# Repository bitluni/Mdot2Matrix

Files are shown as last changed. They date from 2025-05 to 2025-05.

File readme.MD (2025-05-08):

# M.2 LED Matrix

## Goal

This project is a showcase and starting point for M.2 PCIe hardware. The interface chip CH382 was used to inteface between the first PCIe lane and the CH32V208 MCU over UART.
Check out the [versionProject video](https://youtu.be/yxVQkL01FD4)

## State

RTS and DTR control flow signals are used to put the MCU into bootloader. !Caution This version is not working correctly as the signals are flipped on boot etc. Here is an updated [version](https://www.falstad.com/circuit/circuitjs.html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)

In general the interface chip draws 170mA which puts the little LDO at it's limit. The thermals are terrible. Would not recomment to use this setup for a commercial project without a severe refinement.

## Tools

The firmware can be uploaded via the [wch web isp](https://github.com/basilhussain/wch-web-isp)

The code is written with the [MounRiver Studio](http://www.mounriver.com/download)

Node.js is required to run the websocket server

## Vibe coding

The majority of the web tool and the server are generated with ChatGPT which was trained on dacades of mine and your public code.

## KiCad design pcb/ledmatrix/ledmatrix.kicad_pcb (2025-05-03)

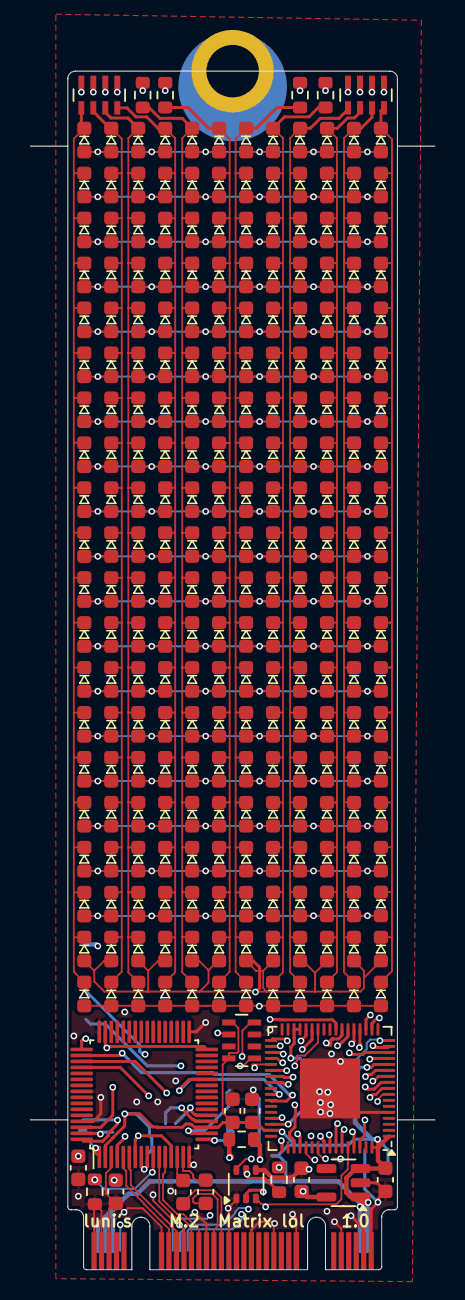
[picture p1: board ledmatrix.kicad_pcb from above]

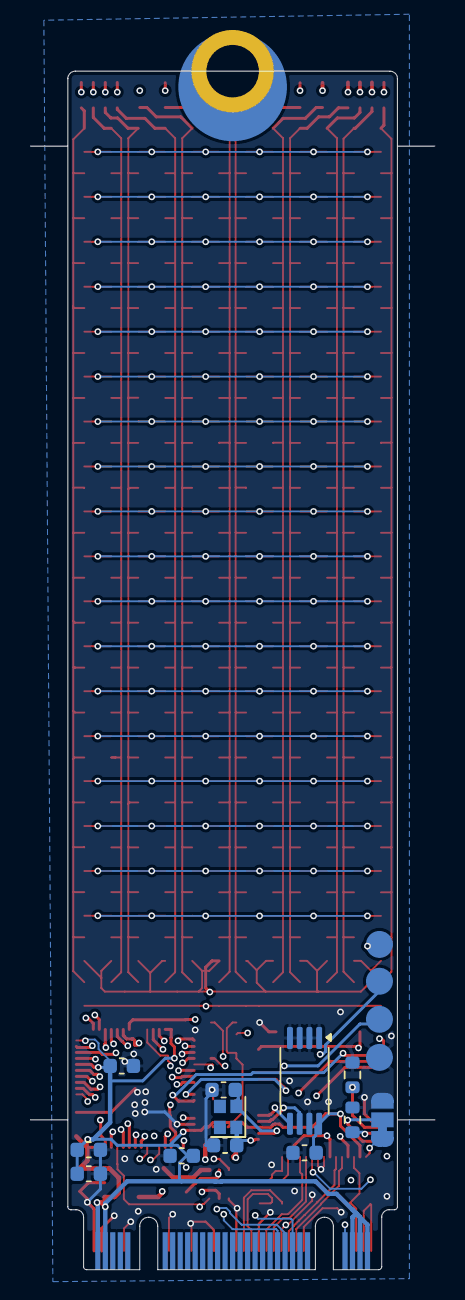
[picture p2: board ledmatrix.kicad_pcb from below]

Board: 4 copper layers, 22.0 x 80.0 mm, 276 parts (13 on the bottom side), 77 nets.

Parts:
C1, C2, C3, C10, C12, C15, C21, C22, C23, C24, C25: 100n; C_0603_1608Metric
C8, C11: 10u; C_0603_1608Metric
C16, C17: 27p; C_0603_1608Metric
D121, D122, D123, D124, D125, D126, D127, D128, D129, D130, D131, D132, D133, D134, D135, D136, D137, D138, D139, D140, D141, D142, D143, D144, D145, D146, D147, D148, D149, D150, D151, D152, D153, D154, D155, D156, D157, D158, D159, D160, D161, D162, D163, D164, D165, D166, D167, D168, D169, D170, D171, D172, D173, D174, D175, D176, D177, D178, D179, D180, D181, D182, D183, D184, D185, D186, D187, D188, D189, D190, D191, D192, D193, D194, D195, D196, D197, D198, D199, D200, D201, D202, D203, D204, D205, D206, D207, D208, D209, D210, D211, D212, D213, D214, D215, D216, D217, D218, D219, D220, D221, D222, D223, D224, D225, D226, D227, D228, D229, D230, D231, D232, D233, D234, D235, D236, D237, D238, D239, D240, D241, D242, D243, D244, D245, D246, D247, D248, D249, D250, D251, D252, D253, D254, D255, D256, D257, D258, D259, D260, D261, D262, D263, D264, D265, D266, D267, D268, D269, D270, D271, D272, D273, D274, D275, D276, D277, D278, D279, D280, D281, D282, D283, D284, D285, D286, D287, D288, D289, D290, D291, D292, D293, D294, D295, D296, D297, D298, D299, D300, D301, D302, D303, D304, D305, D306, D307, D308, D309, D310, D311, D312, D313, D314, D315, D316, D317, D318, D319, D320, D321, D322, D323, D324, D325, D326, D327, D328, D329, D330, D331, D332, D333, D334, D335, D336, D337, D338, D339, D340, D341, D342, D343, D344, D345, D346, D347, D348, D349, D350, D351, D352, D353, D354, D355, D356, D357, D358, D359, D360: LEDdiag0603; LED_0603
JP2: Jumper_3_Bridged12; SolderJumper-3_P1.3mm_Bridged12_RoundedPad1.0x1.5mm
Q1: UMH3N; SOT-363_SC-70-6
R8, R13, R14, R15, R16: 1k; R_0603_1608Metric
R9, R10, R11: 0; R_0603_1608Metric
R12: 12k; R_0603_1608Metric
RN5, RN6: 1k; R_Array_Concave_4x0603
RN8: 10k; R_Array_Concave_4x0603
TP1: TestPoint; Testpoint4
U1: CH382; LQFP-64_7x7mm_P0.4mm
U2: M.2-B+M-KEY-PCIe; M.2-B+M-KEY 2280
U4: M24C02-FDW; TSSOP-8_4.4x3mm_P0.65mm
U5: QFN-68-1EP_8x8mm_P0.4mm_EP4x4mm
U6: AP2112K-1.8; SOT-23-5
Y1: 22.1184MHz; Crystal_SMD_2016-4Pin_2.0x1.6mm

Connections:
1V8: C10.2, C11.2, R9.1, U1.4 (VCC18), U1.32 (VCC18), U1.47 (VCC18), U6.5 (VOUT)
1V8A: C12.2, R9.2, U1.7 (VCC18A), U1.13 (VCC18A)
/BOOT1: R8.2, U5.28 (PB2/BOOT1)
/CKSEL: JP2.2 (C), U1.64 (CKSEL)
/CLKREQ#: RN8.2 (R2.1), U2.P$52 (CLKREQ#)
/CLK_32k: U2.P$68 (SUSCLK(32kHz)), U5.58 (PB3)
/DTR: Q1.2 (B1), U1.52 (DTR0)
/PECK+: U1.5 (PECK+), U2.P$55 (REFCLK+)
/PECK-: U1.6 (PECK-), U2.P$53 (REFCLK-)
/PER+: U1.11 (PER+), U2.P$49 (PER0+)
/PER-: U1.12 (PER-), U2.P$47 (PER0-)
/PET+: C2.2, U1.15 (PET+)
/PET-: C1.2, U1.14 (PET-)
/RST#: JP2.1 (A), U1.1 (PERST#), U2.P$50 (PERST#)
/RST_CH32#: Q1.6 (C1), RN8.8 (R1.2), U5.8 (NRST)
/RTS: Q1.5 (B2), R8.1, U1.51 (RTS0)
/RX: U1.27 (RXD0), U5.44 (PA9)
/TX: U1.50 (TXD0), U5.45 (PA10)
/WAKE#: U2.P$54 (PEWAKE#), U5.56 (PC12)
BOOT0: Q1.3 (C2), RN8.5 (R4.2), U5.63 (BOOT0)
GND: C3.1, C8.1, C10.1, C11.1, C12.1, C15.1, C16.2, C17.2, C21.2, C22.2, C23.2, C24.2, C25.2, JP2.3 (B), Q1.1 (E1), Q1.4 (E2), R10.2, R11.2, R12.2, RN8.7 (R2.2), TP1.1, U1.3 (GND), U1.8 (GND), U1.9 (GND), U1.16 (GND), U1.33 (GND), U1.48 (GND), U1.56 (GND), U1.61 (GND), U2.P$1 (CONFIG3/GND), U2.P$3 (GND), U2.P$9 (GND), U2.P$21 (CONFIG_0/GND), U2.P$27 (GND), U2.P$33 (GND), U2.P$39 (GND), U2.P$45 (GND), U2.P$51 (GND), U2.P$57 (GND), U2.P$71 (GND), U2.P$73 (GND), U2.P$75 (CONFIG_2/GND), U4.1 (E0), U4.2 (E1), U4.3 (E2), U4.4 (VSS), U4.7 (~WC), U5.5 (VSSA), U5.49 (VSS_2), U5.69 (VSS), U6.2 (GND)
unnamed: D121.1 (K), D133.1 (K), D145.1 (K), D157.1 (K), D169.1 (K), D181.1 (K), D193.1 (K), D205.1 (K), D217.1 (K), D229.1 (K), D241.1 (K), D253.1 (K), D265.1 (K), D277.1 (K), D289.1 (K), D301.1 (K), D313.1 (K), D325.1 (K), D337.1 (K), D349.1 (K), RN5.4 (R4.1)
unnamed: D122.1 (K), D134.1 (K), D146.1 (K), D158.1 (K), D170.1 (K), D182.1 (K), D194.1 (K), D206.1 (K), D218.1 (K), D230.1 (K), D242.1 (K), D254.1 (K), D266.1 (K), D278.1 (K), D290.1 (K), D302.1 (K), D314.1 (K), D326.1 (K), D338.1 (K), D350.1 (K), RN5.3 (R3.1)
unnamed: D123.1 (K), D135.1 (K), D147.1 (K), D159.1 (K), D171.1 (K), D183.1 (K), D195.1 (K), D207.1 (K), D219.1 (K), D231.1 (K), D243.1 (K), D255.1 (K), D267.1 (K), D279.1 (K), D291.1 (K), D303.1 (K), D315.1 (K), D327.1 (K), D339.1 (K), D351.1 (K), RN5.2 (R2.1)
unnamed: D124.1 (K), D136.1 (K), D148.1 (K), D160.1 (K), D172.1 (K), D184.1 (K), D196.1 (K), D208.1 (K), D220.1 (K), D232.1 (K), D244.1 (K), D256.1 (K), D268.1 (K), D280.1 (K), D292.1 (K), D304.1 (K), D316.1 (K), D328.1 (K), D340.1 (K), D352.1 (K), RN5.1 (R1.1)
unnamed: D125.1 (K), D137.1 (K), D149.1 (K), D161.1 (K), D173.1 (K), D185.1 (K), D197.1 (K), D209.1 (K), D221.1 (K), D233.1 (K), D245.1 (K), D257.1 (K), D269.1 (K), D281.1 (K), D293.1 (K), D305.1 (K), D317.1 (K), D329.1 (K), D341.1 (K), D353.1 (K), R13.1
unnamed: D126.1 (K), D138.1 (K), D150.1 (K), D162.1 (K), D174.1 (K), D186.1 (K), D198.1 (K), D210.1 (K), D222.1 (K), D234.1 (K), D246.1 (K), D258.1 (K), D270.1 (K), D282.1 (K), D294.1 (K), D306.1 (K), D318.1 (K), D330.1 (K), D342.1 (K), D354.1 (K), R14.1
unnamed: D127.1 (K), D139.1 (K), D151.1 (K), D163.1 (K), D175.1 (K), D187.1 (K), D199.1 (K), D211.1 (K), D223.1 (K), D235.1 (K), D247.1 (K), D259.1 (K), D271.1 (K), D283.1 (K), D295.1 (K), D307.1 (K), D319.1 (K), D331.1 (K), D343.1 (K), D355.1 (K), R15.1
unnamed: D128.1 (K), D140.1 (K), D152.1 (K), D164.1 (K), D176.1 (K), D188.1 (K), D200.1 (K), D212.1 (K), D224.1 (K), D236.1 (K), D248.1 (K), D260.1 (K), D272.1 (K), D284.1 (K), D296.1 (K), D308.1 (K), D320.1 (K), D332.1 (K), D344.1 (K), D356.1 (K), R16.1
unnamed: D129.1 (K), D141.1 (K), D153.1 (K), D165.1 (K), D177.1 (K), D189.1 (K), D201.1 (K), D213.1 (K), D225.1 (K), D237.1 (K), D249.1 (K), D261.1 (K), D273.1 (K), D285.1 (K), D297.1 (K), D309.1 (K), D321.1 (K), D333.1 (K), D345.1 (K), D357.1 (K), RN6.4 (R4.1)
unnamed: D130.1 (K), D142.1 (K), D154.1 (K), D166.1 (K), D178.1 (K), D190.1 (K), D202.1 (K), D214.1 (K), D226.1 (K), D238.1 (K), D250.1 (K), D262.1 (K), D274.1 (K), D286.1 (K), D298.1 (K), D310.1 (K), D322.1 (K), D334.1 (K), D346.1 (K), D358.1 (K), RN6.3 (R3.1)
unnamed: D131.1 (K), D143.1 (K), D155.1 (K), D167.1 (K), D179.1 (K), D191.1 (K), D203.1 (K), D215.1 (K), D227.1 (K), D239.1 (K), D251.1 (K), D263.1 (K), D275.1 (K), D287.1 (K), D299.1 (K), D311.1 (K), D323.1 (K), D335.1 (K), D347.1 (K), D359.1 (K), RN6.2 (R2.1)
unnamed: D132.1 (K), D144.1 (K), D156.1 (K), D168.1 (K), D180.1 (K), D192.1 (K), D204.1 (K), D216.1 (K), D228.1 (K), D240.1 (K), D252.1 (K), D264.1 (K), D276.1 (K), D288.1 (K), D300.1 (K), D312.1 (K), D324.1 (K), D336.1 (K), D348.1 (K), D360.1 (K), RN6.1 (R1.1)
unnamed: R11.1, U1.62 (MDPRT#)
unnamed: R10.1, U1.63 (MDSEL)
unnamed: R12.1, U1.10 (RREF)
unnamed: U1.20 (SCL), U4.6 (SCL)
unnamed: U1.21 (SDA), U4.5 (SDA)
unnamed: C16.1, U1.18 (XI), Y1.2
unnamed: C17.1, U1.17 (XO), Y1.1
unnamed: C2.1, U2.P$43 (PET0+)
unnamed: C1.1, U2.P$41 (PET0-)
PA0: D121.2 (A), D122.2 (A), D123.2 (A), D124.2 (A), D125.2 (A), D126.2 (A), D127.2 (A), D128.2 (A), D129.2 (A), D130.2 (A), D131.2 (A), D132.2 (A), U5.14 (PA0/WKUP/ADC0)
PA1: D133.2 (A), D134.2 (A), D135.2 (A), D136.2 (A), D137.2 (A), D138.2 (A), D139.2 (A), D140.2 (A), D141.2 (A), D142.2 (A), D143.2 (A), D144.2 (A), U5.15 (PA1/ADC1)
PA2: D145.2 (A), D146.2 (A), D147.2 (A), D148.2 (A), D149.2 (A), D150.2 (A), D151.2 (A), D152.2 (A), D153.2 (A), D154.2 (A), D155.2 (A), D156.2 (A), U5.16 (PA2/ADC2)
PA3: D157.2 (A), D158.2 (A), D159.2 (A), D160.2 (A), D161.2 (A), D162.2 (A), D163.2 (A), D164.2 (A), D165.2 (A), D166.2 (A), D167.2 (A), D168.2 (A), U5.19 (PA3/ADC3)
PA4: D169.2 (A), D170.2 (A), D171.2 (A), D172.2 (A), D173.2 (A), D174.2 (A), D175.2 (A), D176.2 (A), D177.2 (A), D178.2 (A), D179.2 (A), D180.2 (A), U5.20 (PA4/ADC4)
PA5: D181.2 (A), D182.2 (A), D183.2 (A), D184.2 (A), D185.2 (A), D186.2 (A), D187.2 (A), D188.2 (A), D189.2 (A), D190.2 (A), D191.2 (A), D192.2 (A), U5.21 (PA5/ADC5)
PA6: D193.2 (A), D194.2 (A), D195.2 (A), D196.2 (A), D197.2 (A), D198.2 (A), D199.2 (A), D200.2 (A), D201.2 (A), D202.2 (A), D203.2 (A), D204.2 (A), U5.22 (PA6/ADC6)
PA7: D205.2 (A), D206.2 (A), D207.2 (A), D208.2 (A), D209.2 (A), D210.2 (A), D211.2 (A), D212.2 (A), D213.2 (A), D214.2 (A), D215.2 (A), D216.2 (A), U5.23 (PA7/ADC7)
PB4: D217.2 (A), D218.2 (A), D219.2 (A), D220.2 (A), D221.2 (A), D222.2 (A), D223.2 (A), D224.2 (A), D225.2 (A), D226.2 (A), D227.2 (A), D228.2 (A), U5.59 (PB4)
PB5: D229.2 (A), D230.2 (A), D231.2 (A), D232.2 (A), D233.2 (A), D234.2 (A), D235.2 (A), D236.2 (A), D237.2 (A), D238.2 (A), D239.2 (A), D240.2 (A), U5.60 (PB5)
PB6: D241.2 (A), D242.2 (A), D243.2 (A), D244.2 (A), D245.2 (A), D246.2 (A), D247.2 (A), D248.2 (A), D249.2 (A), D250.2 (A), D251.2 (A), D252.2 (A), U5.61 (PB6/USB2DM)
PB7: D253.2 (A), D254.2 (A), D255.2 (A), D256.2 (A), D257.2 (A), D258.2 (A), D259.2 (A), D260.2 (A), D261.2 (A), D262.2 (A), D263.2 (A), D264.2 (A), U5.62 (PB7/USB2DP)
PB8: D265.2 (A), D266.2 (A), D267.2 (A), D268.2 (A), D269.2 (A), D270.2 (A), D271.2 (A), D272.2 (A), D273.2 (A), D274.2 (A), D275.2 (A), D276.2 (A), U5.64 (PB8)
PB9: D277.2 (A), D278.2 (A), D279.2 (A), D280.2 (A), D281.2 (A), D282.2 (A), D283.2 (A), D284.2 (A), D285.2 (A), D286.2 (A), D287.2 (A), D288.2 (A), U5.65 (PB9)
PB10: D289.2 (A), D290.2 (A), D291.2 (A), D292.2 (A), D293.2 (A), D294.2 (A), D295.2 (A), D296.2 (A), D297.2 (A), D298.2 (A), D299.2 (A), D300.2 (A), U5.29 (PB10)
PB11: D301.2 (A), D302.2 (A), D303.2 (A), D304.2 (A), D305.2 (A), D306.2 (A), D307.2 (A), D308.2 (A), D309.2 (A), D310.2 (A), D311.2 (A), D312.2 (A), U5.30 (PB11)
PB12: D313.2 (A), D314.2 (A), D315.2 (A), D316.2 (A), D317.2 (A), D318.2 (A), D319.2 (A), D320.2 (A), D321.2 (A), D322.2 (A), D323.2 (A), D324.2 (A), U5.35 (PB12)
PB13: D325.2 (A), D326.2 (A), D327.2 (A), D328.2 (A), D329.2 (A), D330.2 (A), D331.2 (A), D332.2 (A), D333.2 (A), D334.2 (A), D335.2 (A), D336.2 (A), U5.36 (PB13)
PB14: D337.2 (A), D338.2 (A), D339.2 (A), D340.2 (A), D341.2 (A), D342.2 (A), D343.2 (A), D344.2 (A), D345.2 (A), D346.2 (A), D347.2 (A), D348.2 (A), U5.37 (PB14)
PB15: D349.2 (A), D350.2 (A), D351.2 (A), D352.2 (A), D353.2 (A), D354.2 (A), D355.2 (A), D356.2 (A), D357.2 (A), D358.2 (A), D359.2 (A), D360.2 (A), U5.38 (PB15)
PC0: RN5.5 (R4.2), U5.9 (PC0/ADC10)
PC1: RN5.6 (R3.2), U5.10 (PC1/ADC11)
PC2: RN5.7 (R2.2), U5.11 (PC2/ADC12)
PC3: RN5.8 (R1.2), U5.12 (PC3/ADC13)
PC4: R13.2, U5.24 (PC4/ADC14)
PC5: R14.2, U5.25 (PC5/ADC15)
PC6: R15.2, U5.39 (PC6/RXP)
PC7: R16.2, U5.40 (PC7/RXN)
PC8: RN6.5 (R4.2), U5.41 (PC8/TXP)
PC9: RN6.6 (R3.2), U5.42 (PC9/TXN)
PC10: RN6.7 (R2.2), U5.54 (PC10)
PC11: RN6.8 (R1.2), U5.55 (PC11)
SWDCLK: TP1.2, U5.52 (PA14/SWCLK)
SWDIO: TP1.3, U5.48 (PA13/SWDIO)
VCC: C3.2, C8.2, C15.2, C21.1, C22.1, C23.1, C24.1, C25.1, RN8.1 (R1.1), RN8.4 (R4.1), TP1.4, U1.2 (VCC33), U1.19 (VCC33), U1.49 (VCC33), U2.P$2 (3V3), U2.P$4 (3V3), U2.P$70 (3V3), U2.P$72 (3V3), U2.P$74 (3V3), U4.8 (VCC), U5.1 (VBAT), U5.13 (VDDA), U5.17 (VIO_4), U5.31 (VIO_1), U5.32 (VDD_1), U5.50 (VINTA), U5.67 (VIO_3), U5.68 (VDD_3), U6.1 (VIN), U6.3 (EN)

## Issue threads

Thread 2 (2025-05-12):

The code of `main.c` is empty, and the compilation fails.

mayjack0312, 2025-05-12:
The code of `main.c` is empty, and the compilation fails.
The error is reported as follows
```.log
[02:11:15] **** Incremental Build of configuration obj for project Mdot2Matrix ****
make -j16 all
make --no-print-directory main-build
d:/mounriver_studio2/resources/app/resources/win32/components/wch/toolchain/risc-v embedded gcc/bin/../lib/gcc/riscv-none-embed/8.2.0/../../../../riscv-none-embed/bin/ld.exe: ./Startup/startup_ch32v20x_D6.o: in function `.L0 ':
c:\Users\Desktop\Mdot2Matrix-main\firmware\Mdot2Matrix\obj/../Startup/startup_ch32v20x_D6.S:261: undefined reference to `main'
collect2.exe: error: ld returned 1 exit status
make[1]: *** [makefile:58: Mdot2Matrix.elf] Error 1
make: *** [makefile:52: all] Error 2
[02:11:16] Build Failed.
```

mayjack0312, 2025-05-12:
Tried to fix the relevant code, now compile everything is normal

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

```.c
#include "debug.h"
#include <stdint.h>
#include <stdbool.h>

uint64_t *uid = (uint64_t*)0x1ffff7E8;

GPIO_TypeDef *colBank[] = {
    GPIOA, GPIOA, GPIOA, GPIOA, GPIOA, GPIOA, GPIOA, GPIOA,
    GPIOB, GPIOB, GPIOB, GPIOB, GPIOB, GPIOB, GPIOB, GPIOB,
    GPIOB, GPIOB, GPIOB, GPIOB
};

int colPin[] = {
    0, 1, 2, 3, 4, 5, 6, 7,
    4, 5, 6, 7, 8, 9, 10, 11,
    12, 13, 14, 15
};

const int ticksPerBit = 0x80;
#define BIT_DEPTH 8
#define XRES 20
#define YRES 12

uint16_t frame[YRES][XRES];
uint32_t frameBits[2][BIT_DEPTH][XRES];

volatile int currentFrame = 0;
volatile int nextFrame = 0;
volatile uint32_t time = 0;
volatile uint32_t currentBit = 0;
volatile uint32_t currentCol = 0;
volatile uint32_t previousCol = 0;

void __attribute__((interrupt("WCH-Interrupt-fast"))) SysTick_Handler(void)
{
    time++;
    colBank[previousCol]->BCR = 1 << colPin[previousCol];
    GPIOC->OUTDR = frameBits[currentFrame][currentBit][currentCol];
    colBank[currentCol]->BSHR = 1 << colPin[currentCol];
    previousCol = currentCol;
    currentCol++;
    if(currentCol == XRES)
    {
        currentCol = 0;
        currentBit++;
        if(currentBit == BIT_DEPTH)
        {
            currentBit = 0;
            currentFrame = nextFrame;
        }
    }
    SysTick->CMP = ticksPerBit << currentBit;
    SysTick->SR = 0;
}

bool show(void)
{
    if(currentFrame != nextFrame) return false;
    int newFrame = currentFrame ^ 1;

    for(int b = 0; b < BIT_DEPTH; b++)
    {
        for(int x = 0; x < XRES; x++)
        {
            uint32_t bitMask = 0;
            for(int y = 0; y < YRES; y++)
            {
                int bit = (frame[y][x] >> (16 - BIT_DEPTH + b)) & 1;
                bitMask |= bit << y;
            }
            frameBits[newFrame][b][x] = bitMask ^ 0b111111111111;
        }
    }
    nextFrame = newFrame;
    return true;
}

void USART_CFG(void)
{
    GPIO_InitTypeDef GPIO_InitStructure = {0};
    USART_InitTypeDef USART_InitStructure = {0};

    RCC_APB2PeriphClockCmd(RCC_APB2Periph_USART1, ENABLE);
    RCC_APB2PeriphClockCmd(RCC_APB2Periph_GPIOA, ENABLE);

    GPIO_InitStructure.GPIO_Pin = GPIO_Pin_9;
    GPIO_InitStructure.GPIO_Speed = GPIO_Speed_50MHz;
    GPIO_InitStructure.GPIO_Mode = GPIO_Mode_AF_PP;
    GPIO_Init(GPIOA, &GPIO_InitStructure);

    GPIO_InitStructure.GPIO_Pin = GPIO_Pin_10;
    GPIO_InitStructure.GPIO_Mode = GPIO_Mode_IN_FLOATING;
    GPIO_Init(GPIOA, &GPIO_InitStructure);

    USART_InitStructure.USART_BaudRate = 115200;
    USART_InitStructure.USART_WordLength = USART_WordLength_8b;
    USART_InitStructure.USART_StopBits = USART_StopBits_1;
    USART_InitStructure.USART_Parity = USART_Parity_No;
    USART_InitStructure.USART_HardwareFlowControl = USART_HardwareFlowControl_None;
    USART_InitStructure.USART_Mode = USART_Mode_Tx | USART_Mode_Rx;

    USART_Init(USART1, &USART_InitStructure);
    USART_Cmd(USART1, ENABLE);
}

int main(void)
{
    USART_Printf_Init(115200);

    GPIO_InitTypeDef GPIO_InitStructure = {0};

    RCC_APB2PeriphClockCmd(RCC_APB2Periph_GPIOA, ENABLE);
    RCC_APB2PeriphClockCmd(RCC_APB2Periph_GPIOB, ENABLE);
    RCC_APB2PeriphClockCmd(RCC_APB2Periph_GPIOC, ENABLE);

    GPIO_InitStructure.GPIO_Mode = GPIO_Mode_Out_PP;
    GPIO_InitStructure.GPIO_Speed = GPIO_Speed_50MHz;

    for(int i = 0; i < 20; i++)
    {
        GPIO_InitStructure.GPIO_Pin = 1 << colPin[i];
        GPIO_Init(colBank[i], &GPIO_InitStructure);
    }

    GPIOC->CFGLR = ((0b0000 | 0b11) <<  0) | ((0b0000 | 0b11) <<  4) |
                   ((0b0000 | 0b11) <<  8) | ((0b0000 | 0b11) << 12) |
                   ((0b0000 | 0b11) << 16) | ((0b0000 | 0b11) << 20) |
                   ((0b0000 | 0b11) << 24) | ((0b0000 | 0b11) << 28);

    GPIOC->CFGHR = ((0b0000 | 0b11) <<  0) | ((0b0000 | 0b11) <<  4) |
                   ((0b0000 | 0b11) <<  8) | ((0b0000 | 0b11) << 12);

    GPIO_WriteBit(GPIOA, GPIO_Pin_0, Bit_SET);
    GPIO_WriteBit(GPIOC, GPIO_Pin_0, Bit_SET);
    GPIOC->OUTDR = 0b000000000000;
    GPIO_WriteBit(colBank[0], 1 << colPin[0], Bit_SET);

    for(int y = 0; y < YRES; y++)
        for(int x = 0; x < XRES; x++)
            frame[y][x] = (x * YRES + y) * 256;

    show();
    currentFrame = nextFrame;
    show();

    SysTick->SR = 0;
    SysTick->CNT = 0;
    SysTick->CMP = ticksPerBit;
    SysTick->CTLR = 1 | 2 | 4 | 8;
    NVIC_EnableIRQ(SysTicK_IRQn);
    SetVTFIRQ((uint32_t)SysTick_Handler, SysTicK_IRQn, 0, ENABLE);

    while(1)
    {
        static int framePos = 0;
        while(USART_GetFlagStatus(USART1, USART_FLAG_RXNE) == RESET);
        uint8_t c = USART_ReceiveData(USART1);
        if(c >= 'A' && c <= 'F') c += 32;
        if(c == 's')
        {
            framePos = 0;
        }
        else if((c >= '0' && c <= '9') || (c >= 'a' && c <= 'f'))
        {
            int g = (c >= '0' && c <= '9') ? (c - '0') : (c - 'a' + 10);
            frame[0][framePos] = g << 12;
            framePos++;
            if(framePos == XRES * YRES)
            {
                framePos = 0;
                show();
            }
        }
    }
}

```

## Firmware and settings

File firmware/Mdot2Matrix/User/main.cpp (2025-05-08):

#include "debug.h"

uint64_t *uid = (uint64_t*)0x1ffff7E8;

GPIO_TypeDef *colBank[] =     {GPIOA, GPIOA, GPIOA, GPIOA, GPIOA, GPIOA, GPIOA, GPIOA,
                                GPIOB, GPIOB, GPIOB, GPIOB, GPIOB, GPIOB, GPIOB, GPIOB,
                                GPIOB, GPIOB, GPIOB, GPIOB};
int colPin[] =                {0, 1, 2, 3, 4, 5, 6, 7,
                                 4, 5, 6, 7, 8, 9, 10, 11,
                                 12, 13, 14, 15};
//const int ticksPerBit = 0x8000;
const int ticksPerBit = 0x80;
const int bitDepth = 8;
const int xres = 20;
const int yres = 12;
uint16_t frame[yres][xres];
uint32_t frameBits[2][bitDepth][xres];

volatile int currentFrame = 0;
volatile int nextFrame = 0;
volatile uint32_t time = 0;
volatile uint32_t currentBit = 0;
volatile uint32_t currentCol = 0;
volatile uint32_t previousCol = 0;
void __attribute__((interrupt("WCH-Interrupt-fast"))) SysTick_Handler(void)

{
    time++;
    colBank[previousCol]->BCR = 1 << colPin[previousCol];
    GPIOC->OUTDR = frameBits[currentFrame][currentBit][currentCol];
    //GPIOC->OUTDR = 0b111111111111 >> currentCol;//frameBits[currentFrame][currentBit][currentCol];
    colBank[currentCol]->BSHR = 1 << colPin[currentCol];
    previousCol = currentCol;
    currentCol++;
    if(currentCol == xres)
    {
        currentCol = 0;
        currentBit++;
        if(currentBit == bitDepth)
        {
            currentBit = 0;
            currentFrame = nextFrame;
        }
    }
    SysTick->CMP = ticksPerBit << currentBit;
    SysTick->SR=0;
    return;
}

bool show()
{
    if(currentFrame != nextFrame) return false;
    int newFrame = currentFrame ^ 1;
    for(int b = 0; b < bitDepth; b++)
    {
        for(int x = 0; x < xres; x++)
        {
            u_int32_t bitMask = 0;
            for(int y = 0; y < yres; y++)
            {
                int bit = (frame[y][x] >> (16 - bitDepth + b)) & 1;
                bitMask |= bit << y;
            }
            //bitMask = 0b111111111111 >> b;
            frameBits[newFrame][b][x] = bitMask ^ 0b111111111111;   //this matrix has inverted bits
        }
    }
    nextFrame = newFrame;
    return true;
}

void USART_CFG(void)
{
    GPIO_InitTypeDef  GPIO_InitStructure = {0};
    USART_InitTypeDef USART_InitStructure = {0};

    RCC_APB2PeriphClockCmd(RCC_APB2Periph_USART1, ENABLE);
    RCC_APB2PeriphClockCmd(RCC_APB2Periph_GPIOA, ENABLE);

    GPIO_InitStructure.GPIO_Pin = GPIO_Pin_9;
    GPIO_InitStructure.GPIO_Speed = GPIO_Speed_50MHz;
    GPIO_InitStructure.GPIO_Mode = GPIO_Mode_AF_PP;
    GPIO_Init(GPIOA, &GPIO_InitStructure);
    GPIO_InitStructure.GPIO_Pin = GPIO_Pin_10;
    GPIO_InitStructure.GPIO_Mode = GPIO_Mode_IN_FLOATING;
    GPIO_Init(GPIOA, &GPIO_InitStructure);

    USART_InitStructure.USART_BaudRate = 115200;
    USART_InitStructure.USART_WordLength = USART_WordLength_8b;
    USART_InitStructure.USART_StopBits = USART_StopBits_1;
    USART_InitStructure.USART_Parity = USART_Parity_No;
    USART_InitStructure.USART_HardwareFlowControl = USART_HardwareFlowControl_None;
    USART_InitStructure.USART_Mode = USART_Mode_Tx | USART_Mode_Rx;

    USART_Init(USART1, &USART_InitStructure);
    USART_Cmd(USART1, ENABLE);
}


int main(void)
{
    USART_Printf_Init(115200);
    //USART_CFG();

    GPIO_InitTypeDef GPIO_InitStructure = {0};

    RCC_APB2PeriphClockCmd(RCC_APB2Periph_GPIOA, ENABLE);
    RCC_APB2PeriphClockCmd(RCC_APB2Periph_GPIOB, ENABLE);
    RCC_APB2PeriphClockCmd(RCC_APB2Periph_GPIOC, ENABLE);
    GPIO_InitStructure.GPIO_Mode = GPIO_Mode_Out_PP;
    GPIO_InitStructure.GPIO_Speed = GPIO_Speed_50MHz;

    for(int i = 0; i < 20; i++)
    {
        GPIO_InitStructure.GPIO_Pin = 1 << colPin[i];
        GPIO_Init(colBank[i], &GPIO_InitStructure);
    }

    GPIOC->CFGLR =  ((0b0000| 0b11) <<  0) | ((0b0000| 0b11) <<  4) |
                    ((0b0000| 0b11) <<  8) | ((0b0000| 0b11) << 12) |
                    ((0b0000| 0b11) << 16) | ((0b0000| 0b11) << 20) |
                    ((0b0000| 0b11) << 24) | ((0b0000| 0b11) << 28);
    GPIOC->CFGHR =  ((0b0000| 0b11) <<  0) | ((0b0000| 0b11) <<  4) |
                    ((0b0000| 0b11) <<  8) | ((0b0000| 0b11) << 12);
    GPIO_WriteBit(GPIOA, GPIO_Pin_0, Bit_SET);
    GPIO_WriteBit(GPIOC, GPIO_Pin_0, Bit_SET);
    GPIOC->OUTDR = 0b000000000000;
    GPIO_WriteBit(colBank[0], 1 << colPin[0], Bit_SET);
    for(int y = 0; y < yres; y++)
        for(int x = 0; x < xres; x++)
            frame[y][x] = (x * yres + y) * 256;
    show();
    currentFrame = nextFrame;
    show();

    //Delay_Init();

    SysTick->SR = 0;
    SysTick->CNT = 0;
    SysTick->CMP = ticksPerBit;
    SysTick->CTLR = 1 | 2 | 4 | 8;
    NVIC_EnableIRQ(SysTicK_IRQn);
    SetVTFIRQ((u32)SysTick_Handler, SysTicK_IRQn, 0, ENABLE);

    while(1)
    {
        //printf("Juhuuu! It wooorks!\n");
        static int framePos = 0;
        while(USART_GetFlagStatus(USART1, USART_FLAG_RXNE) == RESET);
        u_int8_t c = USART_ReceiveData(USART1);
        if(c >= 'A' && c <= 'F') c+= 32;
        if(c == 's')
            framePos = 0;
        else if((c >= '0' && c <= '9') ||
                (c >= 'a' && c <= 'f'))
        {
            //printf("%c", c);
            int g = 0;
            if(c >= '0' && c <= '9')
                g = c - '0';
            else
                g = c - 'a' + 10;
            frame[0][framePos] = g << 12; //framePos will overflow but trust me it works
            framePos++;
            if(framePos == xres * yres)
            {
                framePos = 0;
                show();
            }
        }
    }
}
